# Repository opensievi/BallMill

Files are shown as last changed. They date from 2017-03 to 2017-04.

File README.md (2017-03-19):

# Open Sievi BallMill controller

This arudino project is to control ball mill motor.

# External libraries

- OneWire
- LiquidCrystal_I2C

# Timers

- 0 = Runtime left
- 1 = Change direction timer
- 2 = Acceleration delay
- 3 = Runtime counter (Increases!)

# Version history

Nothing much here yet

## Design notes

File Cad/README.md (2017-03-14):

CAD models for the 3D printed parts, both freecad and STL, not sure how
useful these are to anyone else but me, but here they are in case you find
them useful.

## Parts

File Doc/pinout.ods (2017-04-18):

OR | +5V
OR / VALK | 0V
VIHR | SCL
VIRH / VALK | SDA
SIN | ROTARY
SIN / VALK | ENCODER
RUS | STARTBTN
RUS / VALK | STOPBTN
HAR | ROTARYBTN
HAR | POT
Pinout
A6 | POT | Har
D9 | MOSFET gate | pun
D12 | Relay IN | RUS
A5 | SCL | Vihr
A4 | SDA | Vihr / valk
D2 | POT +5V | or
D3 | rotary encoder | Sin / valk
D4 | rotary encoder | sin
D5 | rotary encoder btn | har
D6 | stopbtn | Rus / valk
D7 | STARTBTN | rus

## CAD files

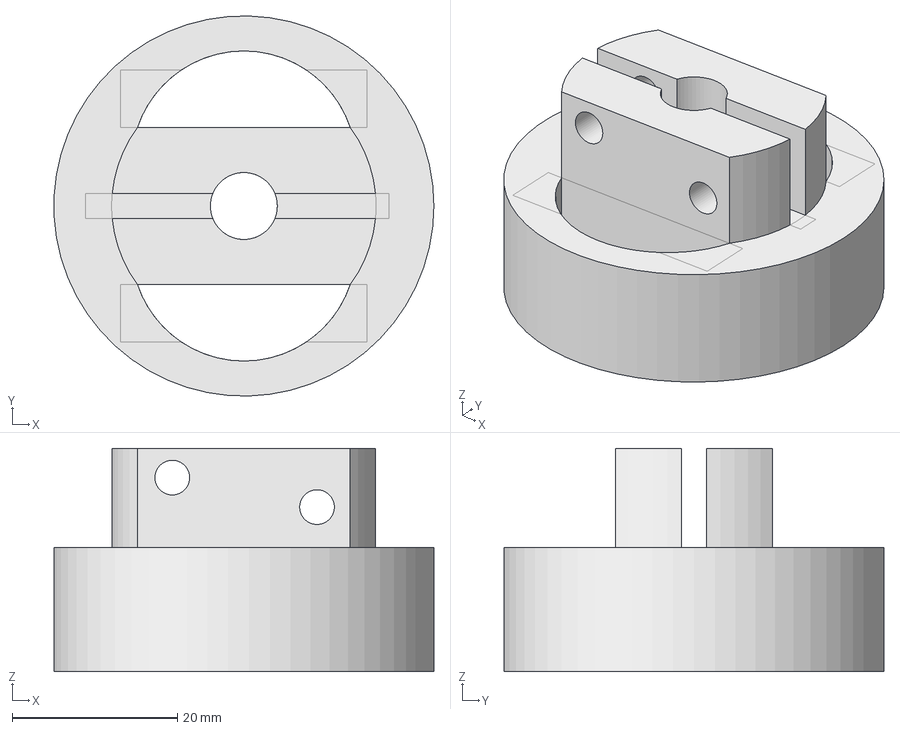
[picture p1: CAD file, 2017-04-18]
Cad/roller_v2.fcstd
46.0 x 46.0 x 27.0 mm

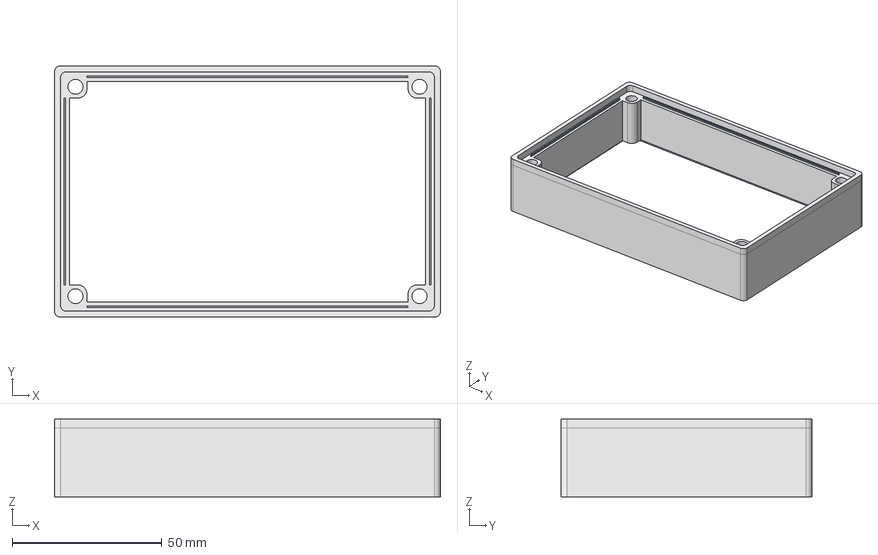
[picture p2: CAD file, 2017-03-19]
Cad/box-riser.fcstd
129.0 x 84.0 x 26.0 mm

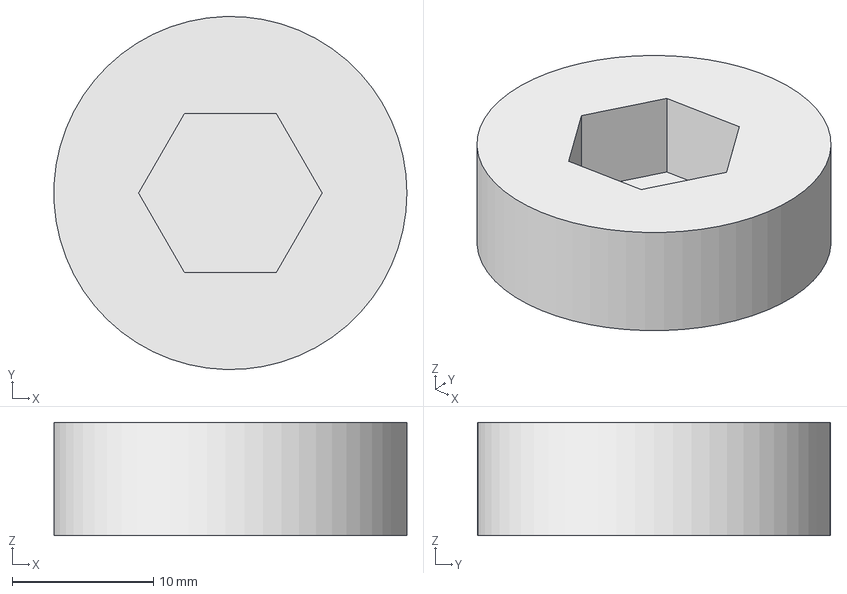
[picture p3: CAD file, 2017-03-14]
Cad/feet-M8.fcstd
25.0 x 25.0 x 8.00 mm

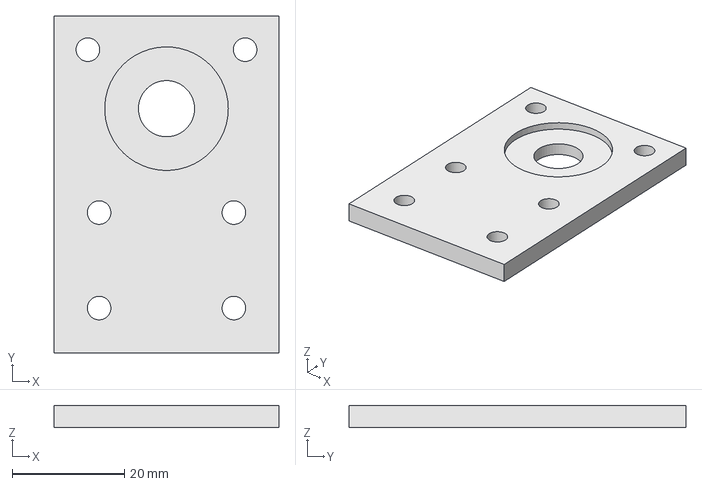
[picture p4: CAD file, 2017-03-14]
Cad/bearing_housing_v2p2.fcstd
40.0 x 60.0 x 4.00 mm

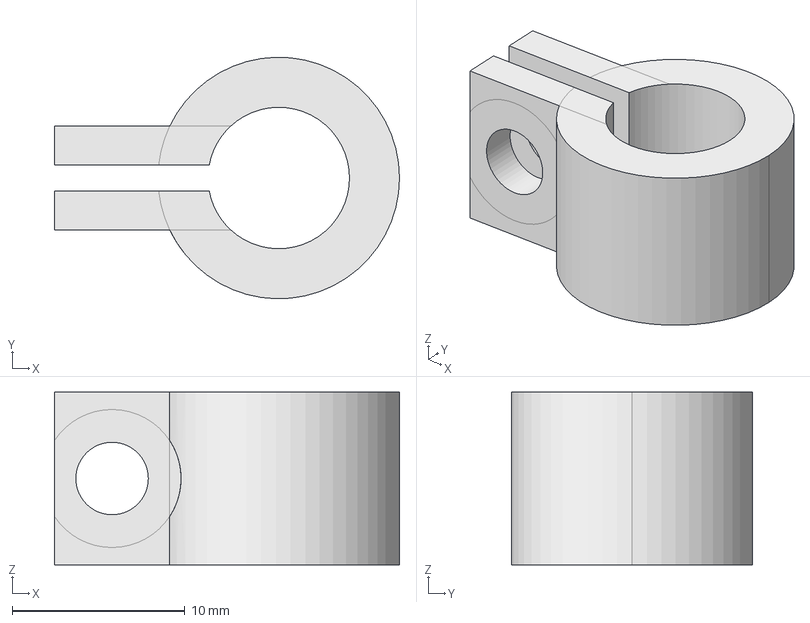
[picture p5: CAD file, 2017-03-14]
Cad/bearingstopper.fcstd
20.0 x 14.0 x 10.0 mm

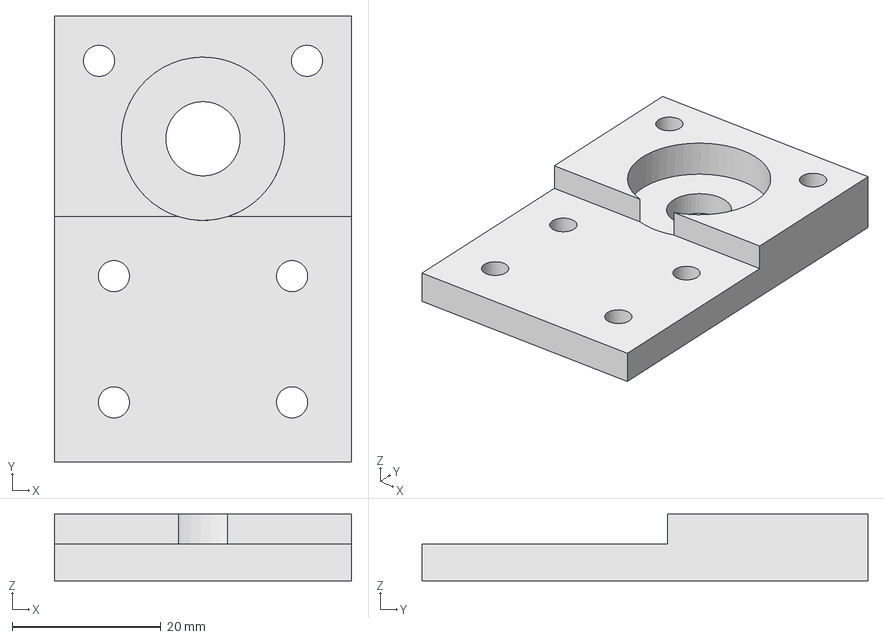
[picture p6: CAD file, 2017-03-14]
Cad/bearing_housing_v2p1.fcstd
40.0 x 60.0 x 9.00 mm

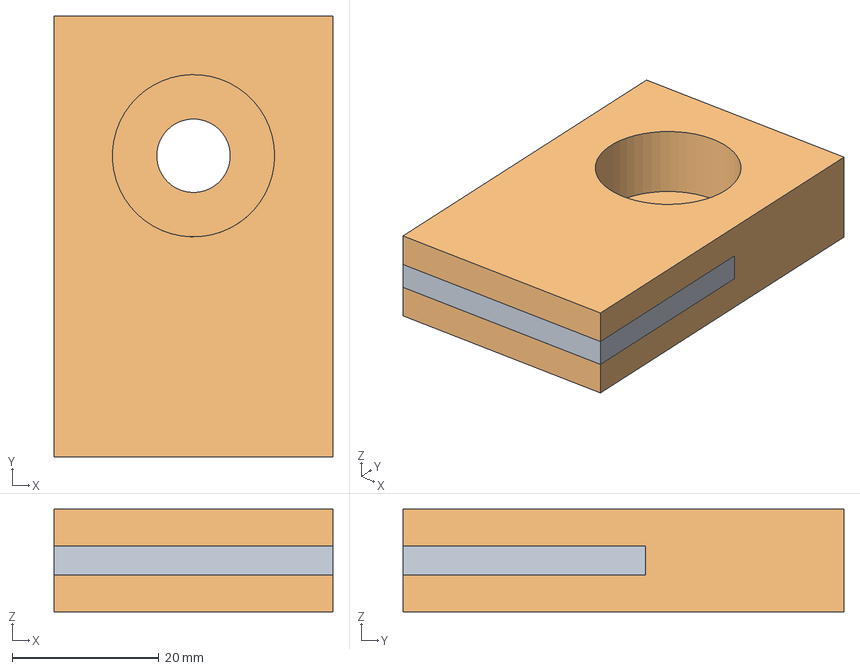
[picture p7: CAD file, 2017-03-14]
Cad/bearing_housing.fcstd
38.0 x 60.0 x 14.0 mm

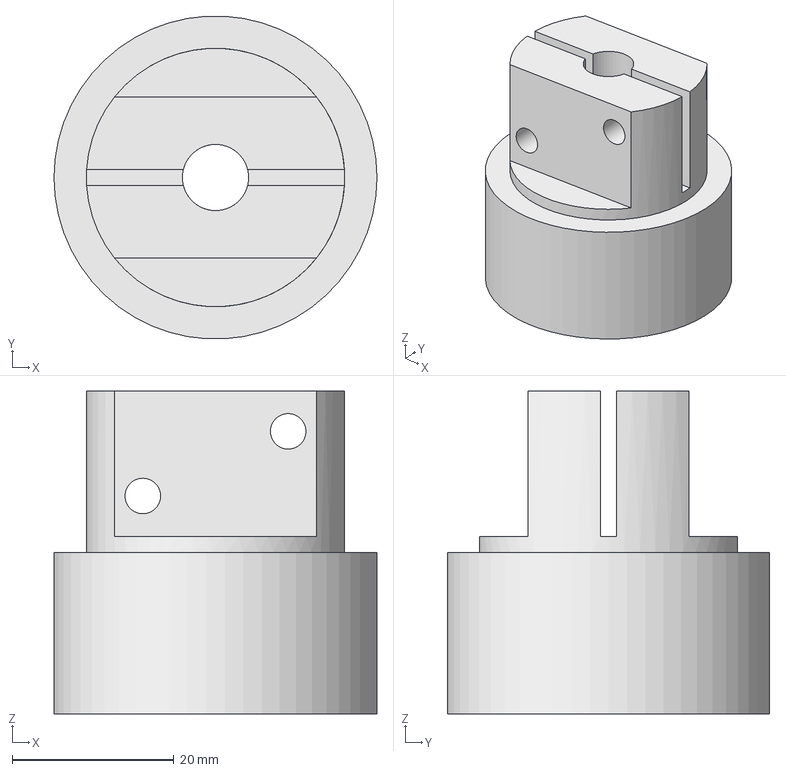
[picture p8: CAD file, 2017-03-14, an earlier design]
Cad/roller.fcstd
40.0 x 39.9 x 40.0 mm

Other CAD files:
Cad/bearing_housing.stl
Cad/bearing_housing_v2p1.stl
Cad/bearing_housing_v2p2.stl
Cad/bearingstopper.stl
Cad/box-riser.stl
Cad/feet-m8.stl
Cad/roller.stl
Cad/roller_v2.stl

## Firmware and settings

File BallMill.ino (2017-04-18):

// OpenSievi BallMill controller
// https://github.com/opensievi/ballmill
//
// Copyright (c) 2017 Tapio Salonsaari <take@nerd.fi>
// 
// This arudino project is to control ball mill motor. Based
// quite heavily on our thermostat project.
//
// See README.md and LICENSE.txt for more info
//

#include <Wire.h>
#include <LiquidCrystal_I2C.h>

#include "PinChangeInt/PinChangeInt.h"

// Software version and writing time
#define SWVERSION "1.1"
#define SWDATE "04-17"

// Behaviour
#define TIMERS 5 // Number of timers
#define BUTTONS 4 // Number of buttons

// Pin layout
#define RELAY_PIN 12
#define MOSFET_PIN 9

#define STARTBTN_PIN 7
#define STOPBTN_PIN 6
#define ROTARYBTN_PIN 5
#define ROTARYFWD_PIN 3
#define ROTARYRWD_PIN 4
#define POT_PIN A6

// LCD used
#define LCD_WIDTH 16
#define LCD_HEIGHT 2
#define LCD_ADDRESS 0x27

// Init subsystems
LiquidCrystal_I2C lcd(LCD_ADDRESS, 2, 1, 0, 4, 5, 6, 7, 3, POSITIVE);

int textState = 0;
int textDelay = 5000;

int cur_phase=0; // current working phase
int cur_running=0; // Run status to track direction change and timer override
int cur_rotation=0; // Which way we're turning
int cur_acceleration=0; // How fast we're turning
int change_speed=0; // track potentiometer changes during run
char phasename[6];
char phasetxt[6];

long timers[TIMERS]; // Countdown timers
long timer_millis; // Internal timer

int timecalc; // Used to calculate spent time

// Default values
unsigned long changeDirection = 300000; // 300000ms = 5min
// 100ms per accel. step * 127 = 12700ms = 12.7 seconds to full speed
unsigned long accelerationDelay = 100; 

// Button handlers
int prev_pot_position=0;
int pot_position=0;
int btn_queue[4];
int rotary_count=0;

// Interrupt function to track down buttons
void trigger_button() {

	int cur_button = PCintPort::arduinoPin;

	switch (cur_button) {
		
		case STARTBTN_PIN:
			btn_queue[0]++;
			break;

		case STOPBTN_PIN:
			btn_queue[1]++;
			break;

		case ROTARYBTN_PIN:
			btn_queue[2]++;
			break;

		default:
			// We don't have this button?
			break;
	}

}

// Interrupt trigger for rotary button, we only
// track the last direction it was turned
void rotary_trigger() {

	int pinA = digitalRead(ROTARYFWD_PIN);
	int pinB = digitalRead(ROTARYRWD_PIN);

	if(pinA != pinB) {
		rotary_count=-1;
	} else {
		rotary_count=1;
	}
}


// Do timer calculations
// This is somewhat hairy since we have incrementing and decreasing
// timers and they're calculated only based on current phases
void countTimers() {

	unsigned long diffMillis = millis() - timer_millis;
	timer_millis = millis();

	for(int i=0;i < TIMERS; i++) {
		
		if(i != 3) {
			if(i == 0) {
				if(cur_phase > 0) {
					timers[i] -= diffMillis;
				}
			} else {
				timers[i] -= diffMillis;
			}
		} else {
			// Only calc time when we're running
			if(cur_running == 2) {
				timers[i] += diffMillis;
			}
		}
		if(timers[i] < 0) {
			timers[i] = 0;
		}
	}

	// Do time tracking calculations. This isn't millisecond
	// accurate, but should be close enough for this purpose.
	timecalc += diffMillis;
	if(timecalc >= 1000) {
		timecalc -= 1000;
	}
	
	return;
}	

// Manage current phase changes, see comments for details
void changePhase() {
	
	switch(cur_phase) {
		case 0: // Standby, we do nothing

			// Reset variables
			cur_rotation = 0;
			cur_acceleration = 0;
			sprintf(phasename,"STDBY");
			sprintf(phasetxt," ");

			break;

		case 1: // Acceleration

			sprintf(phasename,"R %2d%%", int(((float)cur_acceleration/255)*100));
			sprintf(phasetxt,"ACCEL");
			//sprintf(phasetxt,"%d", cur_acceleration);

			if(timers[0] == 0 && cur_running != 2) {
				cur_phase = 3;
				cur_running = 0;
			}

			if(timers[2] == 0) {
				cur_acceleration++;
				timers[2] = accelerationDelay;
				analogWrite(MOSFET_PIN, cur_acceleration);
			} 
			
			int upto;
			upto = int(((float)pot_position/100)*255);

			if(cur_acceleration >= upto) {
				// Acceleration finished, move to
				// stable running
				cur_phase = 2;
			}

			break;
		case 2: // Running

			int dst_spd;
			dst_spd = int(((float)pot_position/100)*255);

			if(cur_acceleration < dst_spd) {
				cur_phase = 1;
			} 

			if(cur_acceleration > dst_spd) {
				cur_phase = 3;
				change_speed = 1;
			}

			sprintf(phasename,"RUN");
			if(cur_rotation == 0) {
				sprintf(phasetxt,">>>>");
			} else {
				sprintf(phasetxt,"<<<<");
			}
			// Change rotation direction
			if(timers[1] == 0) {
				cur_phase = 3;
				if(cur_rotation == 0) {
					cur_rotation = 1;
				} else {
					cur_rotation = 0;
				}
			}

			// Timer finished
			if(timers[0] == 0 && cur_running != 2) {
				cur_phase = 3;
				cur_running = 0;
			}

			if(cur_running == 0) {
				cur_phase = 3;
			}

			break;
		case 3: // Deceleration

			int dest;
			dest = 0;
			if(change_speed) {
				dest = int(((float)pot_position/100)*255);
			}

			sprintf(phasename,"R %2d%%", int(((float)cur_acceleration/255)*100));
			sprintf(phasetxt,"DECEL");
			if(timers[2] == 0) {
				cur_acceleration--;
				timers[2] = accelerationDelay;
				analogWrite(MOSFET_PIN, cur_acceleration);
			} 
			
			if(cur_running == 0) {
				sprintf(phasename,"STOP");
			}
				
			if(cur_acceleration <= dest) {
				// Decelration finished
				if(cur_running > 0) {
					change_speed = 0;
					cur_phase = 2;
					if(timers[1] == 0) {
						timers[1] = changeDirection;
						if(cur_rotation) {
							digitalWrite(RELAY_PIN, LOW);
						} else {
							digitalWrite(RELAY_PIN, HIGH);
						}
					}
				} else {
					// If we stopped
					digitalWrite(RELAY_PIN, HIGH);
					digitalWrite(MOSFET_PIN, LOW);
					cur_phase = 0;
				}
			}
		
			break;
		default:
			// Something goes BADLY wrong if this
			// ever happens. We go to infinite loop
			// and shut everything down.
			char buf[20];
			digitalWrite(RELAY_PIN,HIGH); // Shut off burner
			while(1) {
				lcd.home();
				lcd.print("PHASE ERROR            ");
				lcd.setCursor(0,1);
				sprintf(buf,"Phase: %d              ",cur_phase);
				lcd.print(buf);
				delay(10000);
			}
			break;
	}
}

// Function: Setup
//
// Initialize subsystems and start main loop
//
void setup() {
	char version[20];	
	Serial.begin(9600);

	// Output pins
	pinMode(RELAY_PIN, OUTPUT);
	pinMode(MOSFET_PIN, OUTPUT);

	// Input pins
	pinMode(STARTBTN_PIN, INPUT_PULLUP);
	pinMode(STOPBTN_PIN, INPUT_PULLUP);
	pinMode(ROTARYBTN_PIN, INPUT_PULLUP);
	pinMode(ROTARYFWD_PIN, INPUT_PULLUP);
	pinMode(ROTARYRWD_PIN, INPUT_PULLUP);
	pinMode(POT_PIN, INPUT);

	// Initialize interrupts
	attachPinChangeInterrupt(STARTBTN_PIN, trigger_button, FALLING);
	attachPinChangeInterrupt(STOPBTN_PIN, trigger_button, FALLING);
	attachPinChangeInterrupt(ROTARYBTN_PIN, trigger_button, FALLING);
	attachPinChangeInterrupt(ROTARYFWD_PIN, rotary_trigger, CHANGE);

	// Initialize timers
	for(int i=0;i < TIMERS;i++) {
		timers[i] = 0;
	}

	// Initialize button counters
	for(int i=0; i < BUTTONS; i++) {
		btn_queue[i] = 0;
	}

	// Our relay pulls when RELAY_PIN is LOW, this is somewhat
	// inconvinient, but it should work out just fine
	digitalWrite(RELAY_PIN, HIGH);

	lcd.begin(LCD_WIDTH, LCD_HEIGHT); // initialize the lcd 
	lcd.home(); // go home

	// Output some version information on startup
	lcd.print("O-S BallMill");  
	lcd.setCursor ( 0, 1 );        // go to the next line
	sprintf(version, "ver %s %s", SWVERSION, SWDATE);
	lcd.print (version);
	delay ( 1500 );

	lcd.clear();
	return;
}

// Main loop
void loop() {
	char buf[20];
	char buf2[20];

	//pot_position = map(analogRead(POT_PIN), 0, 1023, 100, 0);
	//Serial.println(pot_position);
			
	// Add / subtract a 5 minutes from timer when rotary switch is turned
	if(cur_phase == 0) {
		if(rotary_count == 1) {
			timers[0]+=300000;
			rotary_count = 0;
		} 

		if(rotary_count == -1) {
			timers[0]-=300000;
			// Don't go below 0
			if(timers[0] < 0) {
				timers[0] = 0;
			}
			rotary_count = 0;
		}
	} else {
		if(rotary_count == 1) {
			rotary_count = 0;

			if(cur_running > 0) {
				pot_position++;
				if(pot_position > 100) {
					pot_position = 100;
				}
			}
		}
		if(rotary_count == -1) {
			rotary_count = 0;
			if(cur_running > 0) {
				pot_position--;
				if(pot_position < 0) {
					pot_position = 0;
				}
			}
		}
	}

	// If stop button is pressed
	if(btn_queue[1] > 0) {
		timers[0]=0;
		btn_queue[1]=0;
		change_speed=0;
		cur_phase = 3;
		cur_running = 0;
		pot_position = 0;
	}

	// If start button is pressed
	if(btn_queue[0] > 0) {
		btn_queue[0] = 0;
		if(cur_phase == 0) {
			timers[1] = changeDirection;
			timers[2] = 0;
			timers[3] = 0;
			pot_position = 0;
			cur_acceleration = 0;
			if(timers[0] == 0) {
				cur_running = 2;
			} else {
				cur_running = 1;
			}
			cur_phase = 1;
		}
	}

	countTimers(); // Manage time calculations
	changePhase(); // Manage phases

	int time_calc[2];
	int tmp_time;

	if(timers[4] == 0) {
		if(textState==0) {
			textState=1;
		} else {
			textState=0;
		}
		timers[4]=textDelay;
	}

	if(textState==0 || cur_phase == 0) {
		if(cur_running == 2) {
			tmp_time = timers[3] / 1000;
		} else {
			tmp_time = timers[0] / 1000;
		}
	} else {
		tmp_time = timers[1] / 1000;
	}

	time_calc[0] = tmp_time / 60 /60;
	tmp_time -= time_calc[0]*60*60;
	time_calc[1] = tmp_time / 60;
	tmp_time -= time_calc[1]*60;
	time_calc[2] = tmp_time;

	if(textState == 0 || cur_phase == 0) {
		if(cur_running == 2) {
			sprintf(buf2, "Run : %02dh%02dm%02ds", time_calc[0], time_calc[1], time_calc[2]);
		} else {
			sprintf(buf2, "Time: %02dh%02dm%02ds", time_calc[0], time_calc[1], time_calc[2]);
		}
	} else {
		sprintf(buf2, "Turn: %02dh%02dm%02ds", time_calc[0], time_calc[1], time_calc[2]);
	}

	sprintf(buf, "%-5s %3d%% %5s", phasename, pot_position, phasetxt);

	lcd.setCursor(0,0);
	lcd.print(buf);
	lcd.setCursor(0,1);
	lcd.print(buf2);

}

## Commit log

2017-03-14 Misc files to help with the project
    [ballmill.fzz, bearing_housing.fcstd, bearing_housing.stl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]
2017-03-19 Various helper files and one submodule
    [box-riser.fcstd, box-riser.stl]
2017-03-19 1st version of arduino code, needs cleanup and some refining, but it mostly works.
2017-03-20 Version 1.0, everything should work now
    [pinout.ods]
2017-03-22 Duh, PWM output is from digital pin, not analog.
    [pinout.ods]
2017-04-18 Removal of potentiometer and more info on display
    For some reason electric circuit caused the potentiometer to act unpredictable,
    most likely due to adding large capacitor on the circuit. Potentiometer is now
    removed and it's functionality is replaced with rotary encoder.
    [pinout.ods, roller_v2.fcstd, roller_v2.stl]
